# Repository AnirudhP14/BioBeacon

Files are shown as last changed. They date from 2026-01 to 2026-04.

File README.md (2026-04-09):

# BioBeacon

ESP32 based stigmergic swarm built on esp-now.

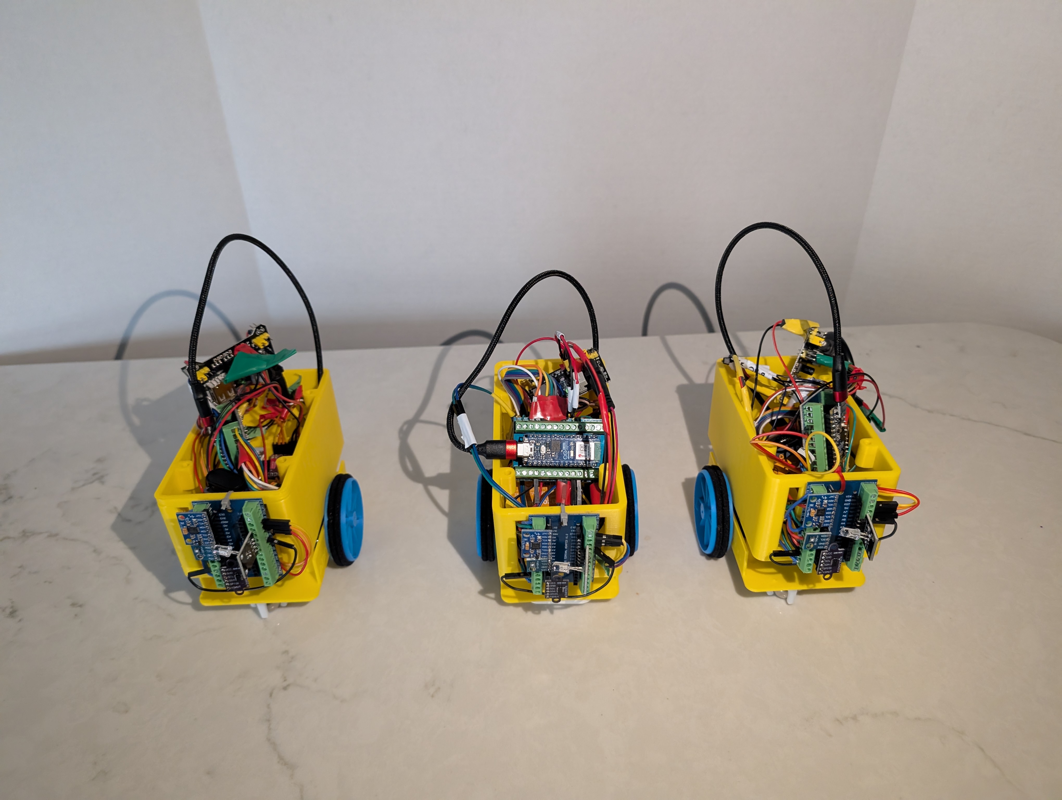
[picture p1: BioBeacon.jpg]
BioBeacon


# HiveMind - BioBeacon's swarm monitoring
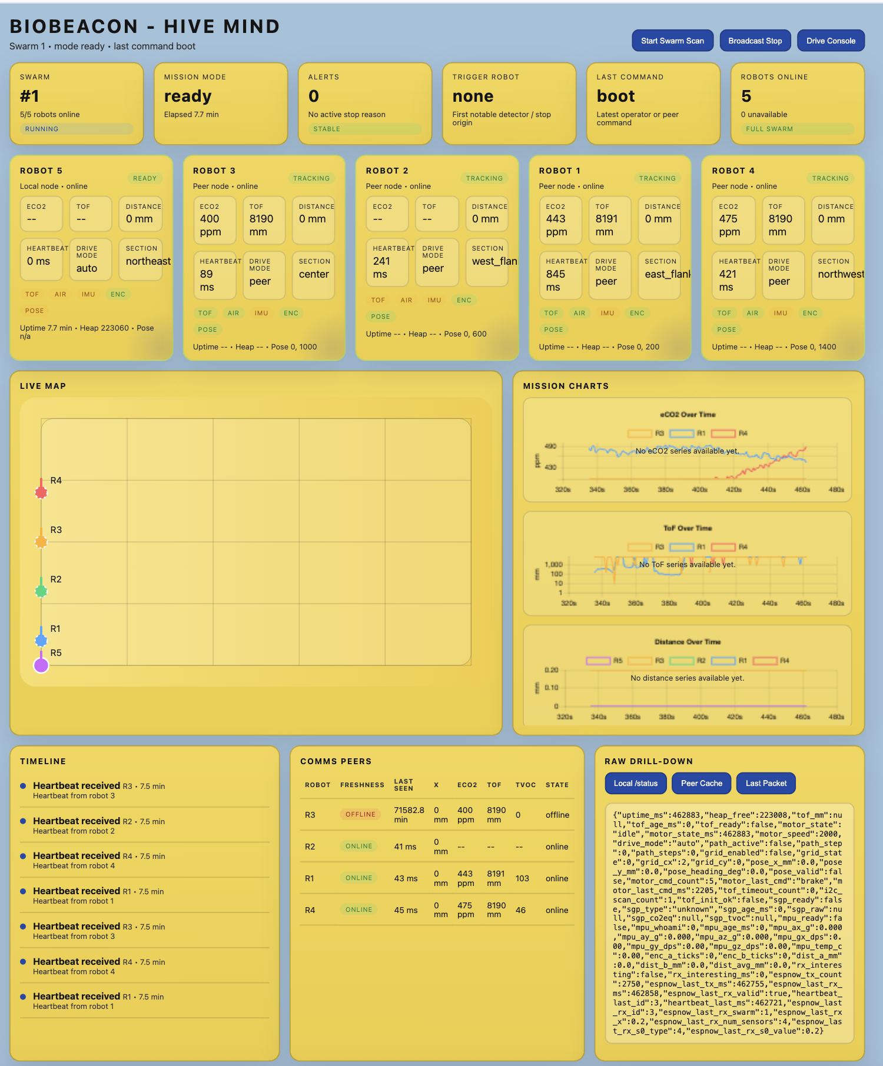
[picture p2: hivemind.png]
HiveMind


# Custom PCB for BioBeacob
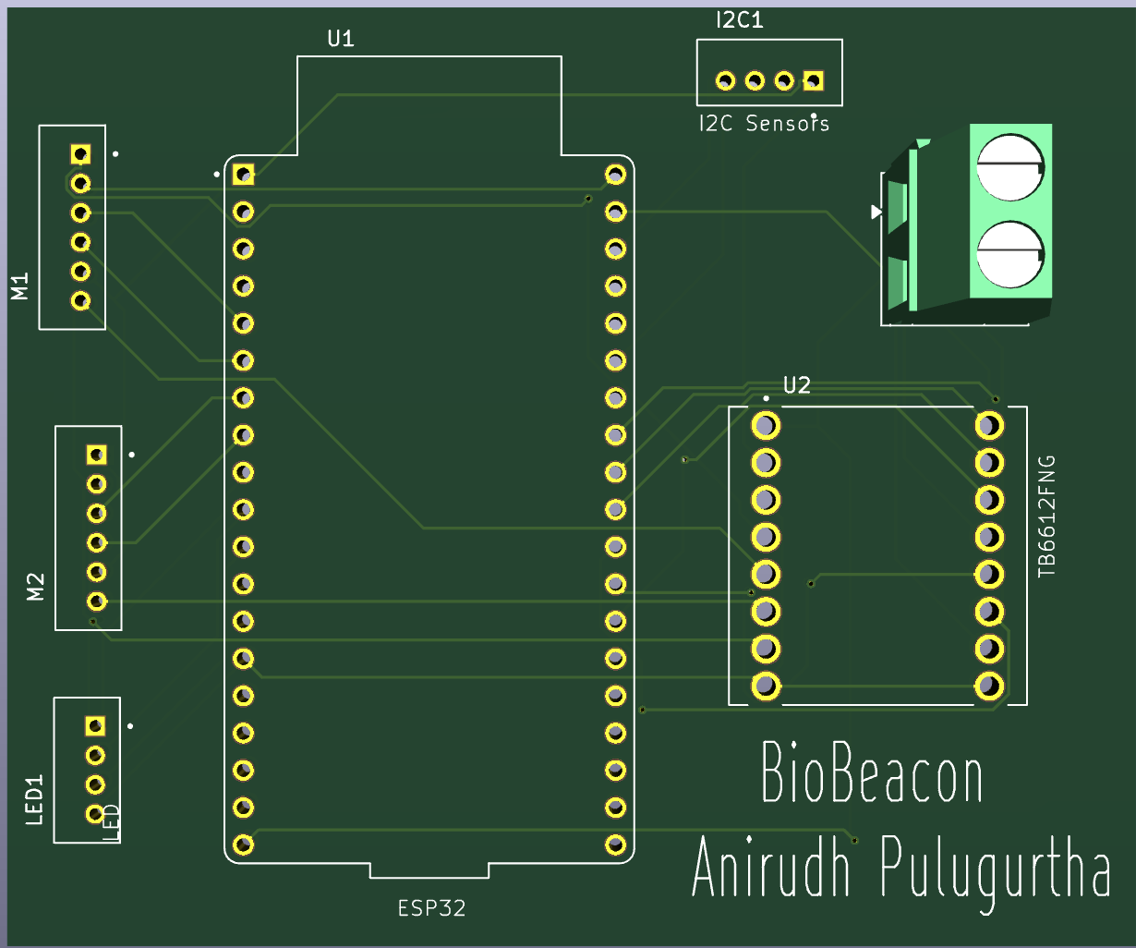
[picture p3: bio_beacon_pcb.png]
BioBeacon ESP32 PCB


white a01
red a02

white b01
red b02

Left motor encoder C1 → ENCA_C1 (GPIO2). green  D2
Left motor encoder C2 → ENCA_C2 (GPIO3).  yellow D3
Right motor encoder C1 → ENCB_C1 (GPIO11) green D11
Right motor encoder C2 → ENCB_C2 (GPIO12) yellow D12

Enc VCC - black 
Enc Gnd - purple

D0	GPIO44
D1	GPIO43
D2	GPIO5
D3	GPIO6
D4	GPIO7
D5	GPIO8
D6	GPIO9
D7	GPIO10
D8	GPIO17
D9	GPIO18
D10	GPIO21
D11	GPIO38
D12	GPIO47
D13	GPIO48
A0	GPIO1
A1	GPIO2
A2	GPIO3
A3	GPIO4
A4	GPIO11
A5	GPIO12
A6	GPIO13
A7	GPIO14
BOOT0	GPIO46
BOOT1	GPIO0

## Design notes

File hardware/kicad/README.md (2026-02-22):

# Kicad pcb files

This folder contains Ki-cad PCB files for
- BioBeacon ESP32 Wroom board
- BioBeacon sensor board - daughter board
- TB6612FNG motor board 

Additional ESP32 boards to be added to support additional ESP32 variants.
Separate TB6612FNG daughter board could provide more flexibility.

# Custom PCB for BioBeacob
BioBeacon ESP32 PCB

# Schematic for BioBeacon Motherboard 
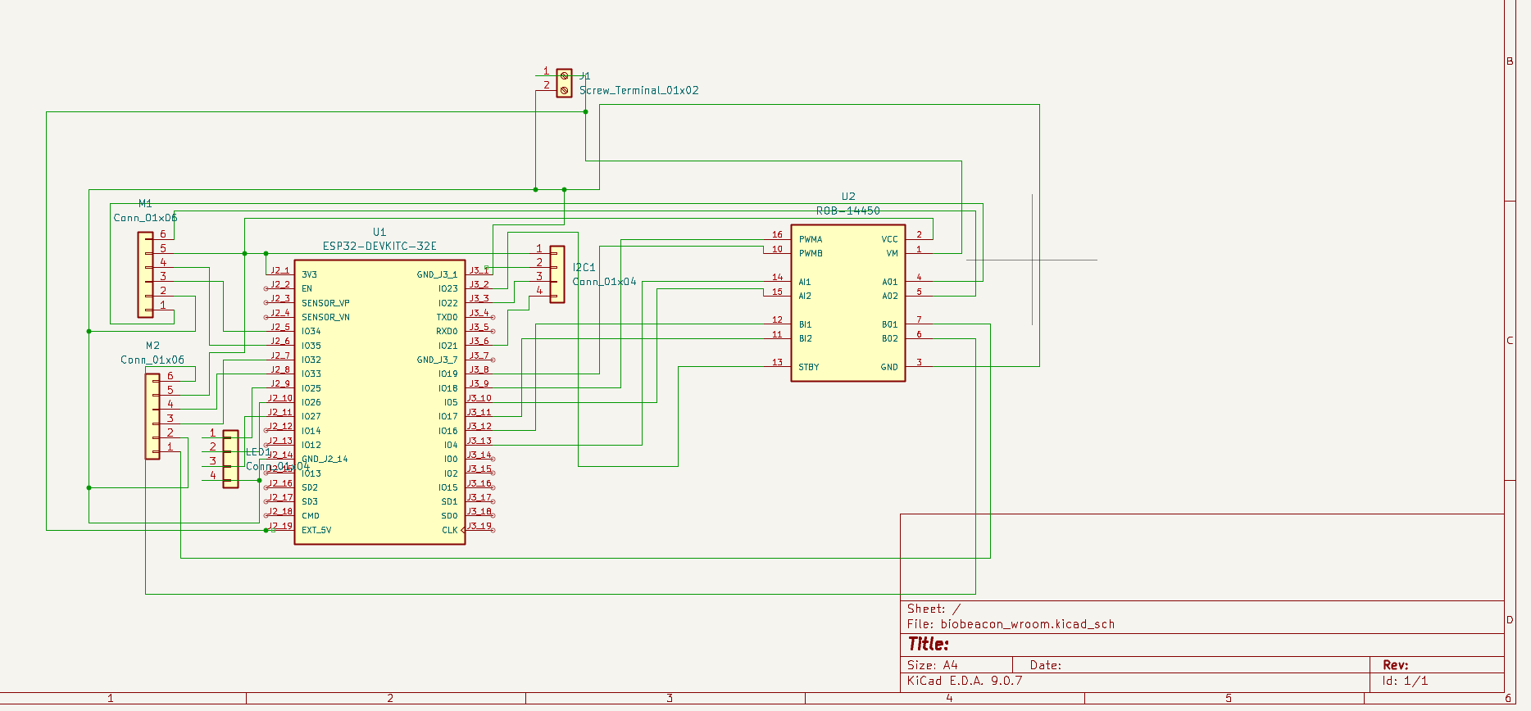
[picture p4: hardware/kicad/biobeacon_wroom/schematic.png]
BioBeacon Motherboard Schematic


# Sensorboard daugther board 
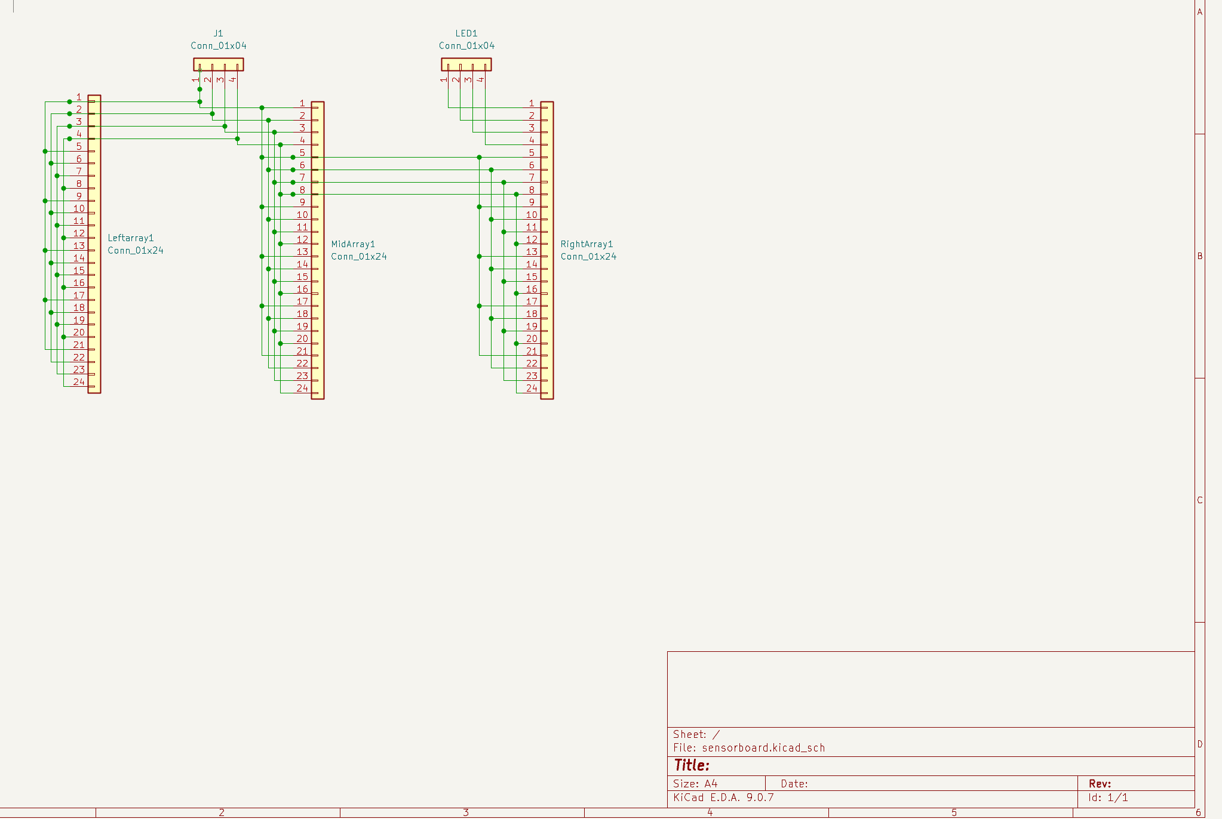
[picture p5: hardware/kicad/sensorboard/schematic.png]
BioBeacon sensorboard Schematic

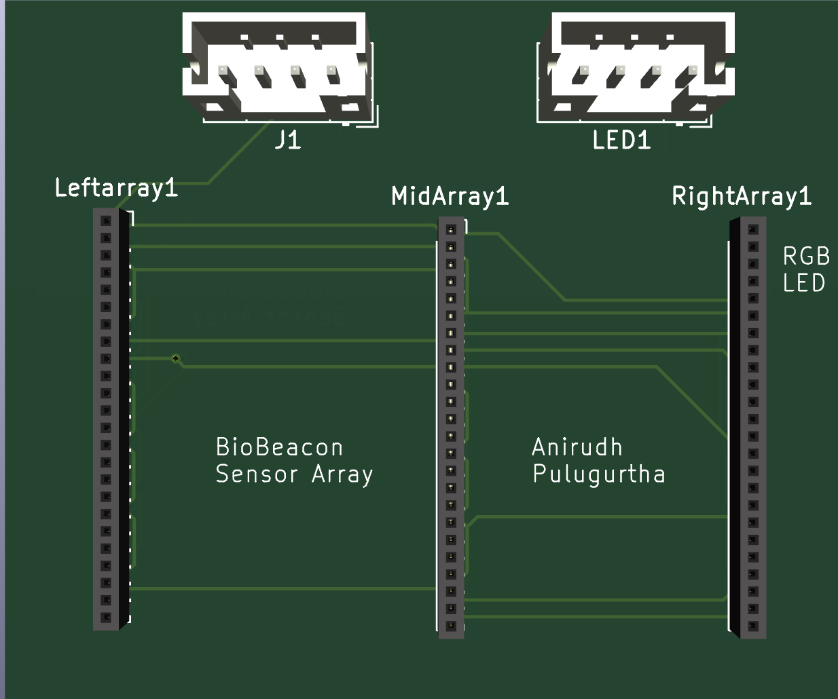
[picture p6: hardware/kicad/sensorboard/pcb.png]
BioBeacon sensorboard Schematic


# Motor driver daugther board 
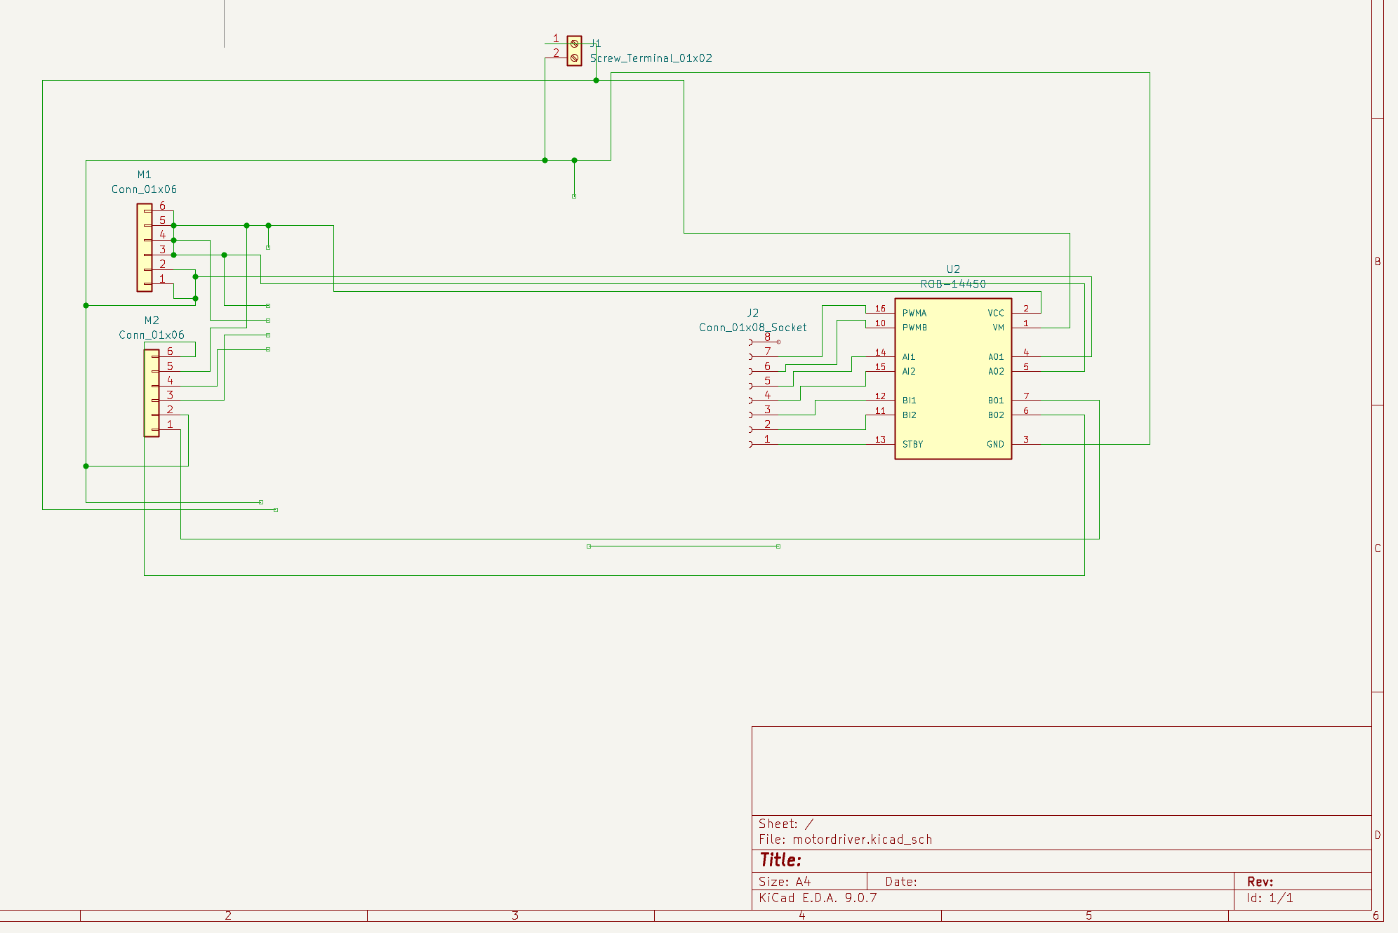
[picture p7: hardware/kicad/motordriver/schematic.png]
BioBeacon motordriver only Schematic

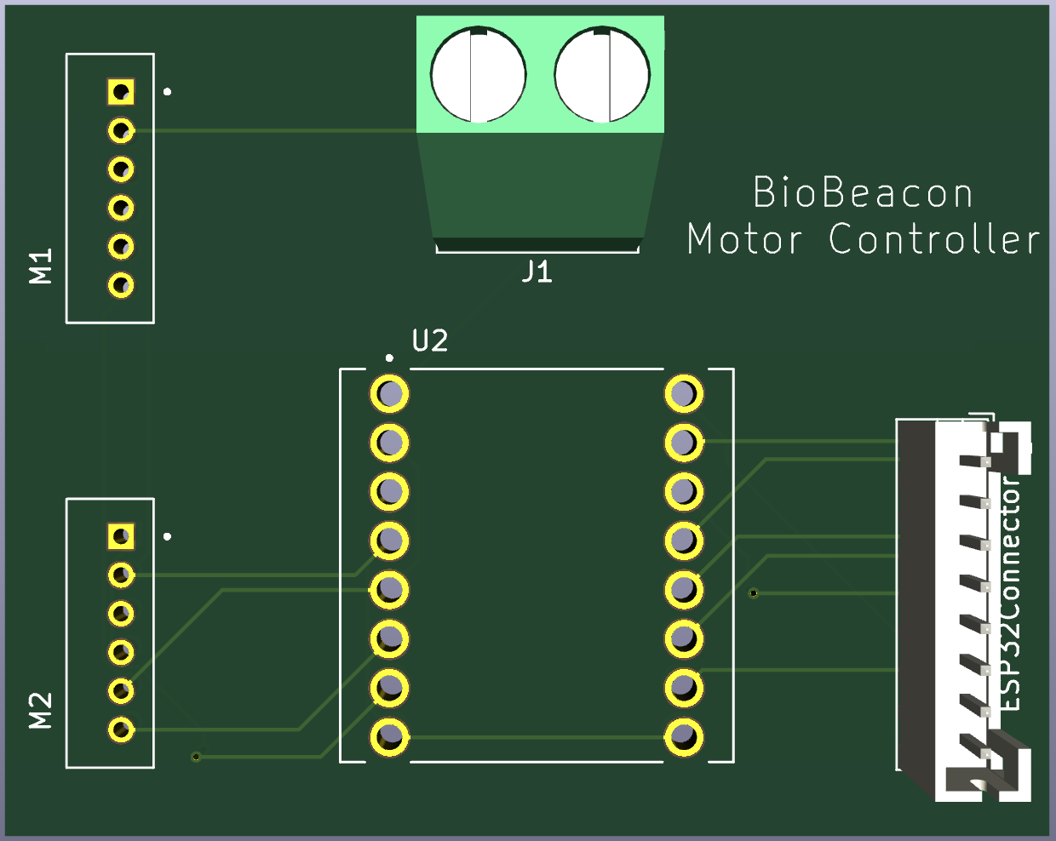
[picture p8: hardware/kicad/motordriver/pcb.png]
BioBeacon motordriver Schematic


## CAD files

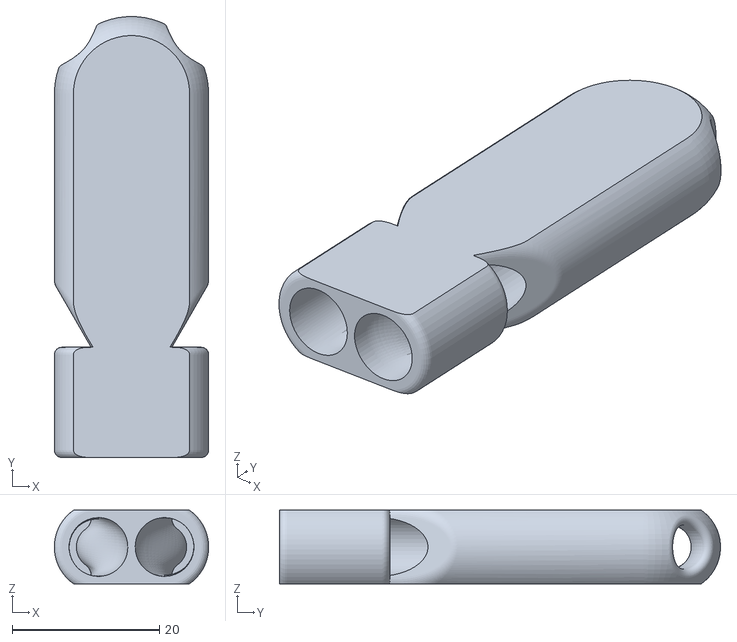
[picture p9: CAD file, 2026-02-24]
hardware/cad-3d-prints/rescue_tools_3d_print_files/whistle.stl
21.0 x 60.0 x 10.0

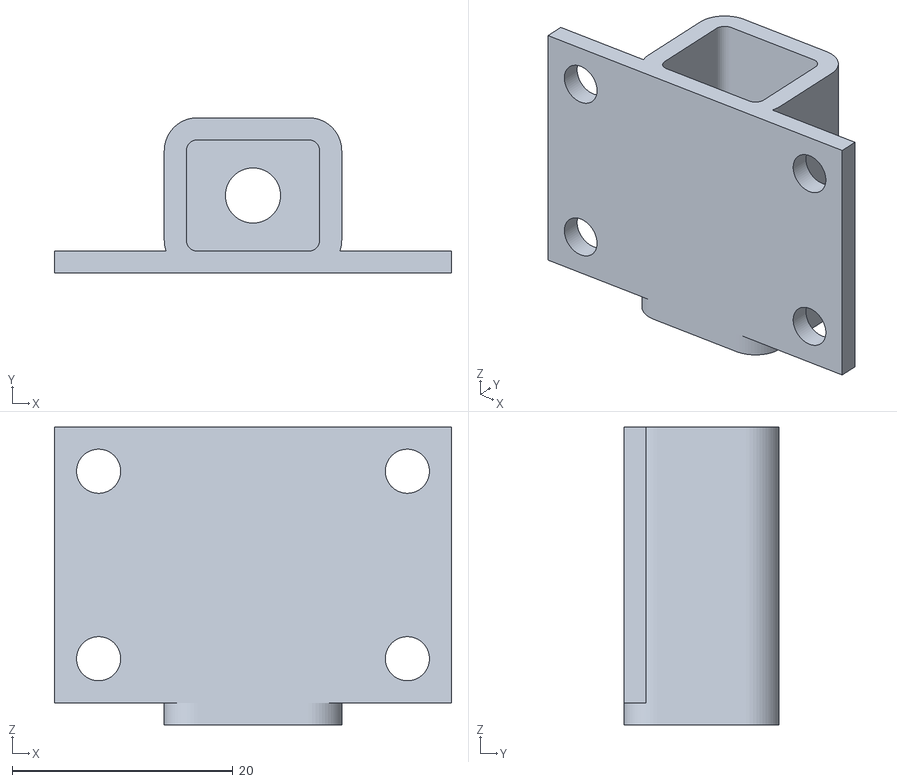
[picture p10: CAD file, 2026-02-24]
hardware/cad-3d-prints/robot_3d_print_files/N20MotorMounts.stl
36.0 x 14.1 x 27.0

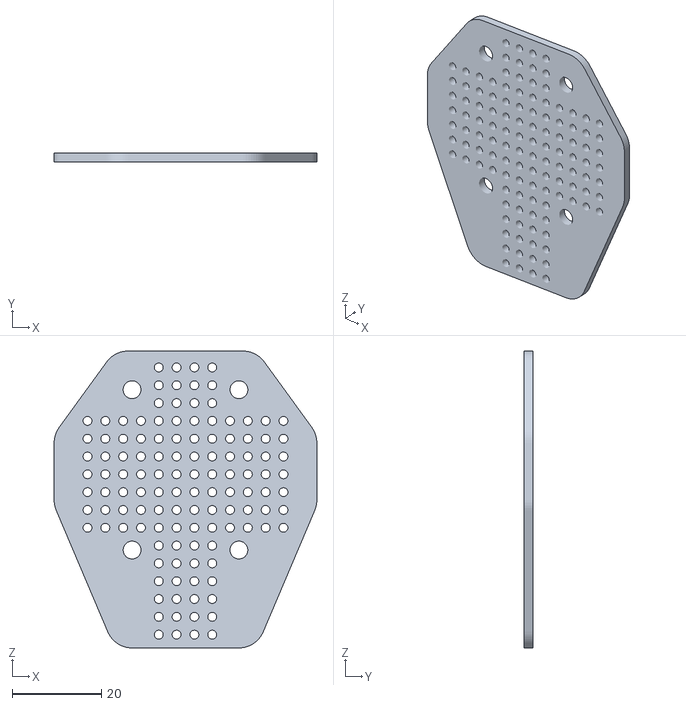
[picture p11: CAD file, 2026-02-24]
hardware/cad-3d-prints/robot_3d_print_files/robo_lid.stl
59.0 x 2.00 x 66.7

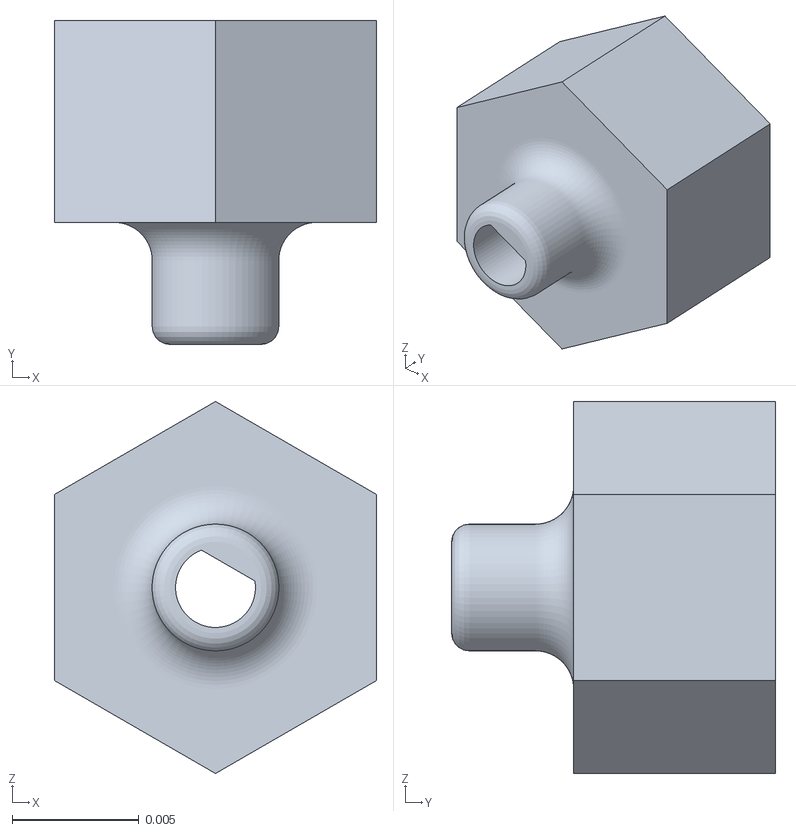
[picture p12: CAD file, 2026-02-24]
hardware/cad-3d-prints/robot_3d_print_files/Wheel.stl
0.0127 x 0.0128 x 0.0147

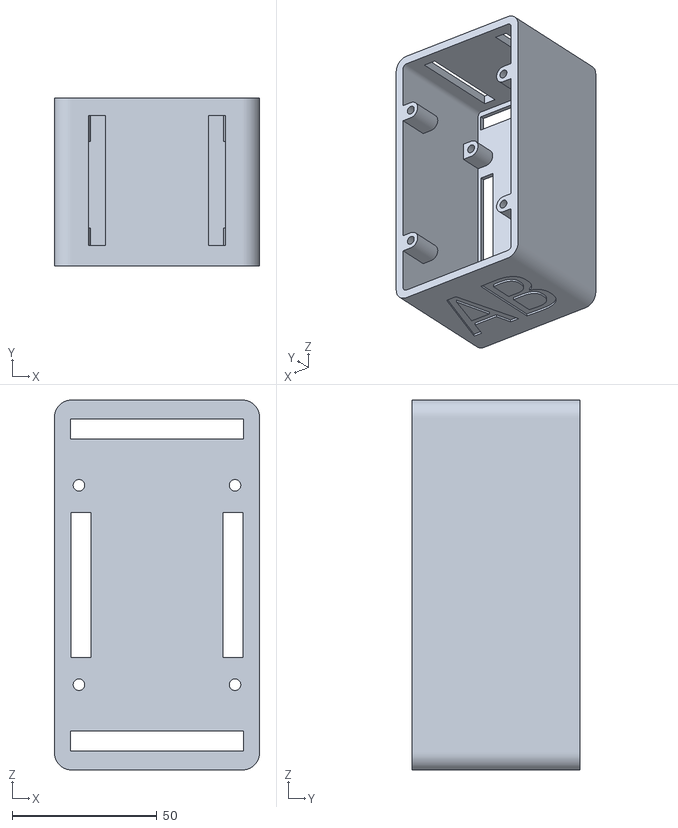
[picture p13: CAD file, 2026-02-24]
hardware/cad-3d-prints/robot_3d_print_files/robo_mid_box.stl
71.0 x 58.0 x 128.0

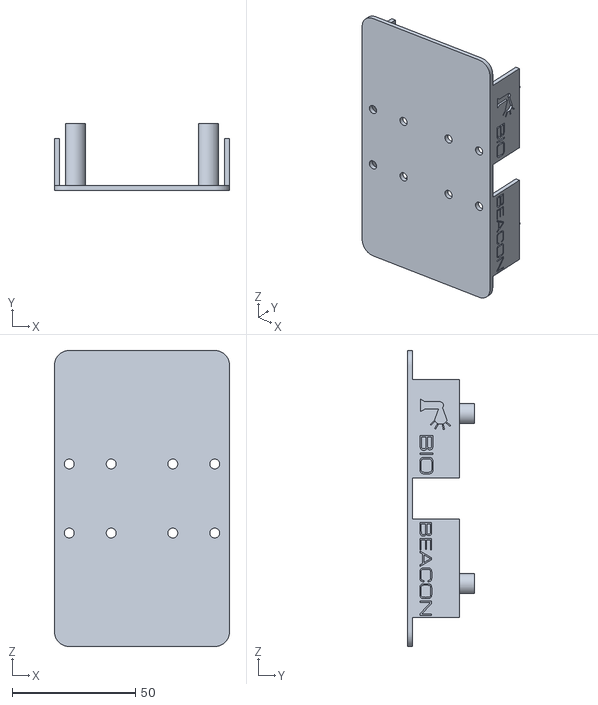
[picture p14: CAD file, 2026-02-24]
hardware/cad-3d-prints/robot_3d_print_files/robo_base.stl
71.0 x 27.0 x 120.0

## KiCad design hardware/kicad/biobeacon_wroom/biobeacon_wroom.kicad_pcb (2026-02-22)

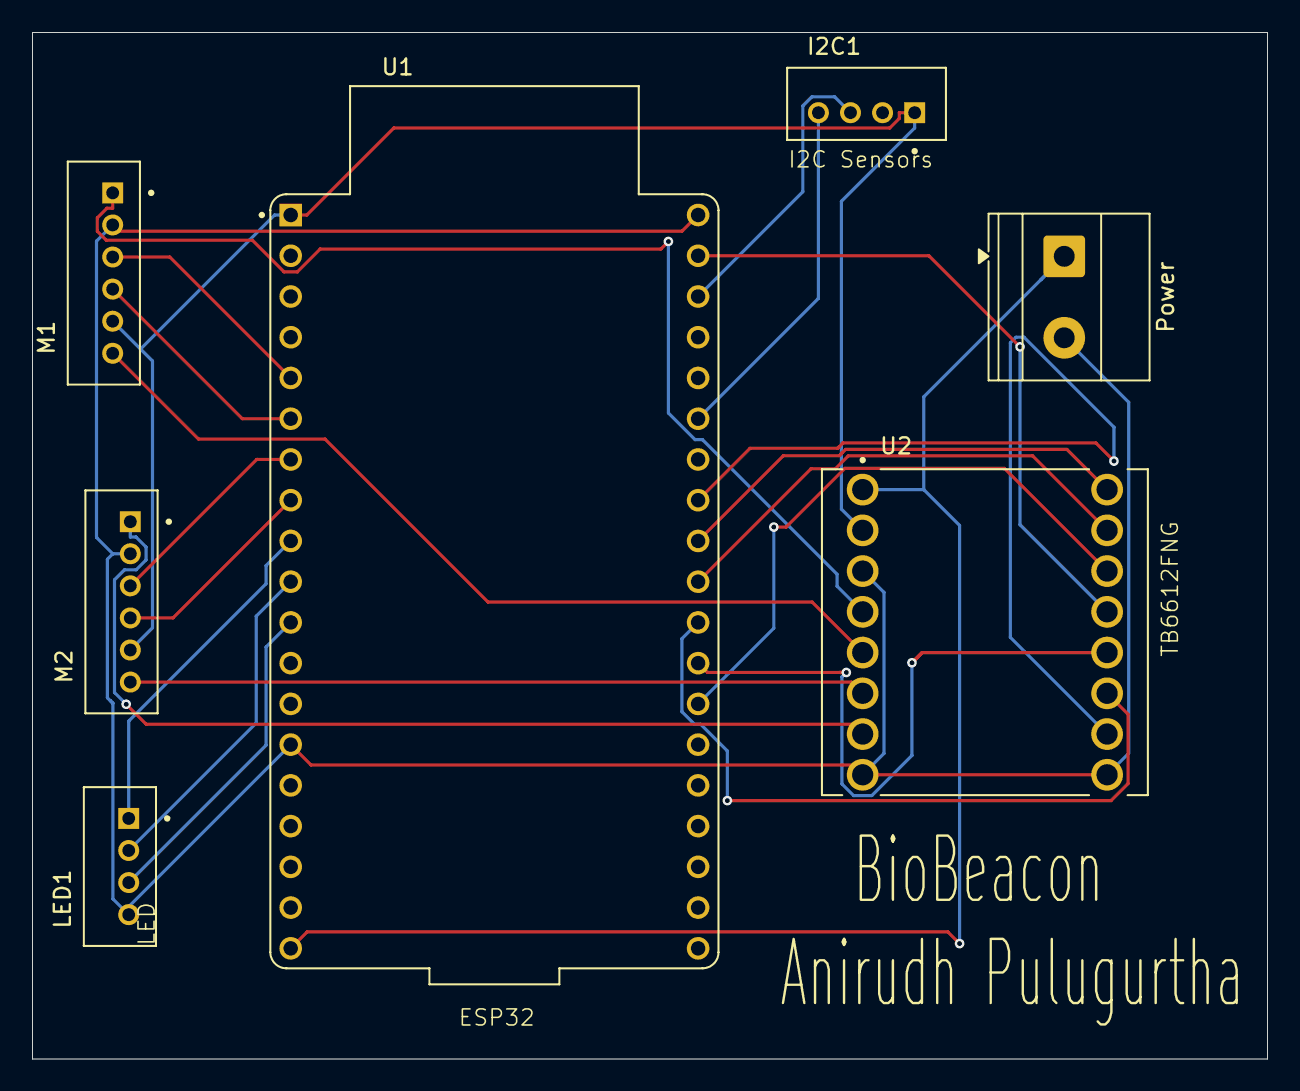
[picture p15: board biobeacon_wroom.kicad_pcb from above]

Board: 2 copper layers, 77.0 x 64.0 mm, 7 parts (0 on the bottom side), 23 nets.

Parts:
I2C1: Conn_01x04; JST_B4B-PH-K
LED1: Conn_01x04; JST_B4B-PH-K
M1, M2: Conn_01x06; JST_B6B-PH-K
Power: Screw_Terminal_01x02; TerminalBlock_Phoenix_MKDS-1,5-2-5.08_1x02_P5.08mm_Horizont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
U1: ESP32-DEVKITC-32E; MODULE_ESP32-DEVKITC-32E
U2: ROB-14450; MODULE_ROB-14450

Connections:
GND: LED1.4, M1.2, M2.2, Power.2, U1.J2_14 (GND_J2_14), U1.J3_1 (GND_J3_1), U2.3 (GND), U2.8 (GND), U2.9 (GND)
unnamed: I2C1.1, M1.5, M2.5, U1.J2_1 (3V3), U2.2 (VCC)
unnamed: I2C1.3, U1.J3_3 (IO22)
unnamed: I2C1.4, U1.J3_6 (IO21)
unnamed: Power.1, U1.J2_19 (EXT_5V), U2.1 (VM)
unnamed: LED1.1, U1.J2_9 (IO25)
unnamed: LED1.2, U1.J2_10 (IO26)
unnamed: LED1.3, U1.J2_11 (IO27)
unnamed: M1.1, U2.4 (A01)
unnamed: M1.3, U1.J2_5 (IO34)
unnamed: M1.4, U1.J2_6 (IO35)
unnamed: M1.6, U2.5 (A02)
unnamed: M2.1, U2.7 (B01)
unnamed: M2.3, U1.J2_7 (IO32)
unnamed: M2.4, U1.J2_8 (IO33)
unnamed: M2.6, U2.6 (B02)
unnamed: U1.J3_13 (IO4), U2.14 (AI1)
unnamed: U1.J3_10 (IO5), U2.15 (AI2)
unnamed: U1.J3_12 (IO16), U2.12 (BI1)
unnamed: U1.J3_11 (IO17), U2.11 (BI2)
unnamed: U1.J3_9 (IO18), U2.16 (PWMA)
unnamed: U1.J3_8 (IO19), U2.10 (PWMB)
unnamed: U1.J3_2 (IO23), U2.13 (STBY)

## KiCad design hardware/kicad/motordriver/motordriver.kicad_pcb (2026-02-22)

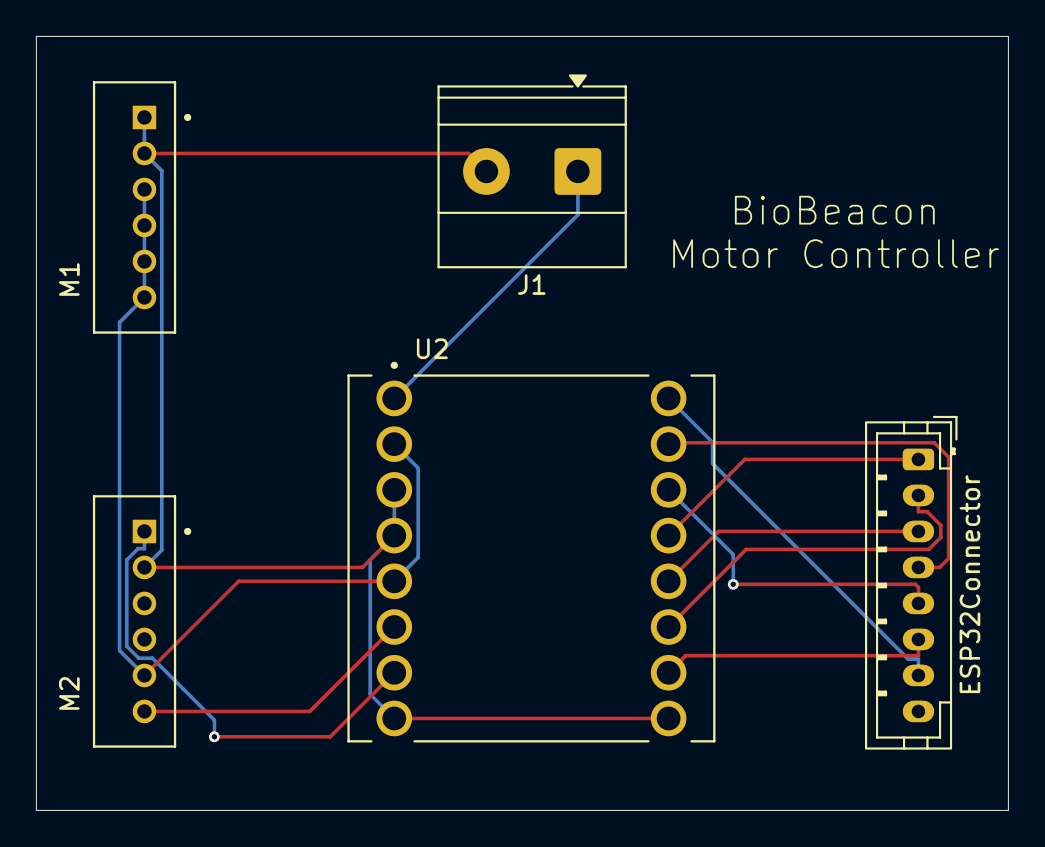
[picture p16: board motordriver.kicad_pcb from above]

Board: 2 copper layers, 54.0 x 43.0 mm, 5 parts (0 on the bottom side), 12 nets.

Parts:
ESP32Connector: Conn_01x08_Socket; JST_PH_B8B-PH-K_1x08_P2.00mm_Vertical
J1: Screw_Terminal_01x02; TerminalBlock_Phoenix_MKDS-1,5-2-5.08_1x02_P5.08mm_Horizont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
M1, M2: Conn_01x06; JST_B6B-PH-K
U2: ROB-14450; MODULE_ROB-14450

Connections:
GND: J1.2, M1.1, M1.2, M2.2, U2.3 (GND), U2.4 (A01), U2.8 (GND), U2.9 (GND)
unnamed: J1.1, U2.1 (VM)
unnamed: ESP32Connector.1, U2.13 (STBY)
unnamed: ESP32Connector.2, U2.11 (BI2)
unnamed: ESP32Connector.3, U2.12 (BI1)
unnamed: ESP32Connector.4, U2.15 (AI2)
unnamed: ESP32Connector.5, U2.14 (AI1)
unnamed: ESP32Connector.6, U2.10 (PWMB)
unnamed: ESP32Connector.7, U2.16 (PWMA)
unnamed: M1.3, M1.4, M1.5, M1.6, M2.5, U2.2 (VCC), U2.5 (A02)
unnamed: M2.1, U2.7 (B01)
unnamed: M2.6, U2.6 (B02)

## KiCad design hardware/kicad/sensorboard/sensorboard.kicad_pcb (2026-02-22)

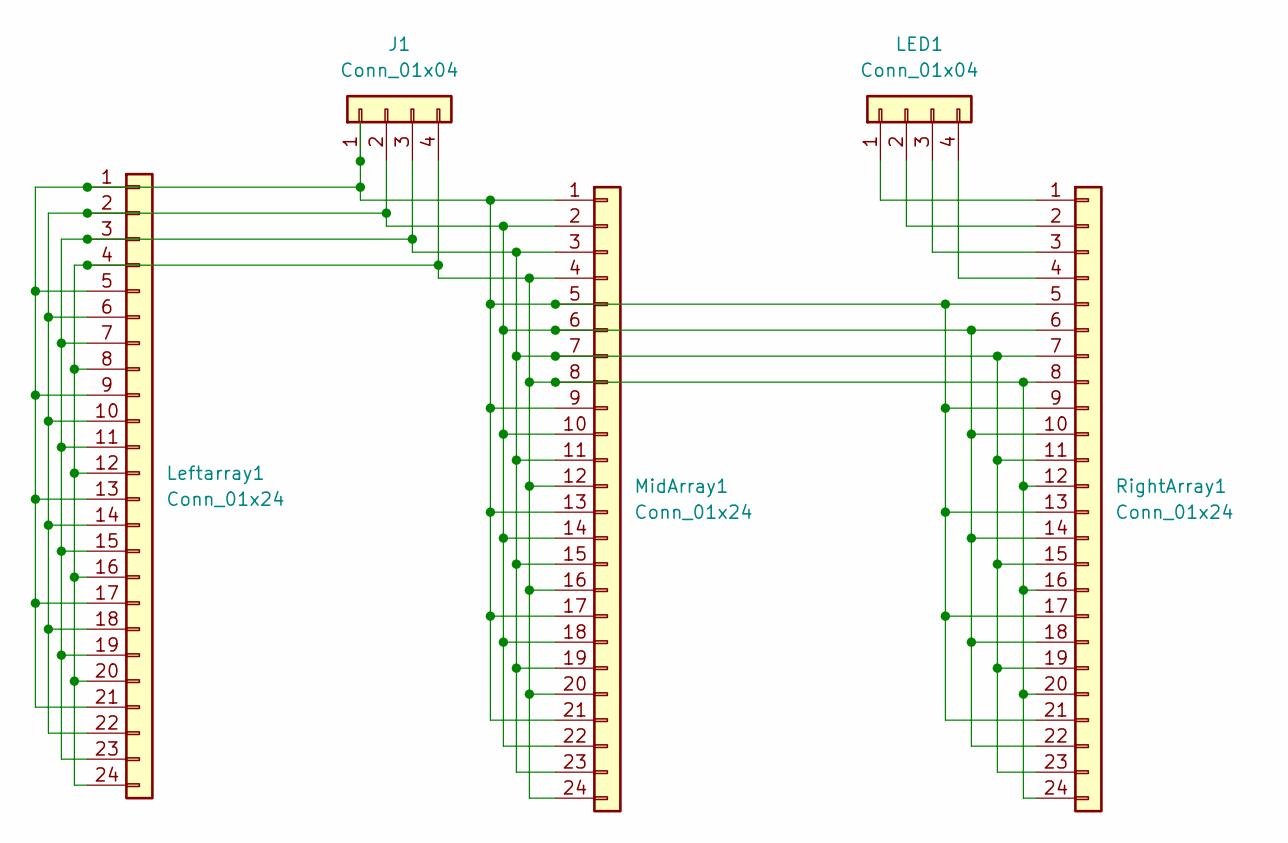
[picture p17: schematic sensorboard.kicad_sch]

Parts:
J1: Conn_01x04; JST_PH_B4B-PH-K_1x04_P2.00mm_Vertical
LED1: Conn_01x04; JST_PH_B4B-PH-K_1x04_P2.00mm_Vertical
Leftarray1: Conn_01x24; PinSocket_1x24_P1.00mm_Vertical
MidArray1: Conn_01x24; PinSocket_1x24_P1.00mm_Vertical
RightArray1: Conn_01x24; PinSocket_1x24_P1.00mm_Vertical

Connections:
unnamed: J1.1, Leftarray1.1, Leftarray1.5, Leftarray1.9, Leftarray1.13, Leftarray1.17, Leftarray1.21, MidArray1.1, MidArray1.5, MidArray1.9, MidArray1.13, MidArray1.17, MidArray1.21, RightArray1.5, RightArray1.9, RightArray1.13, RightArray1.17, RightArray1.21
unnamed: J1.2, Leftarray1.2, Leftarray1.6, Leftarray1.10, Leftarray1.14, Leftarray1.18, Leftarray1.22, MidArray1.2, MidArray1.6, MidArray1.10, MidArray1.14, MidArray1.18, MidArray1.22, RightArray1.6, RightArray1.10, RightArray1.14, RightArray1.18, RightArray1.22
unnamed: J1.3, Leftarray1.3, Leftarray1.7, Leftarray1.11, Leftarray1.15, Leftarray1.19, Leftarray1.23, MidArray1.3, MidArray1.7, MidArray1.11, MidArray1.15, MidArray1.19, MidArray1.23, RightArray1.7, RightArray1.11, RightArray1.15, RightArray1.19, RightArray1.23
unnamed: J1.4, Leftarray1.4, Leftarray1.8, Leftarray1.12, Leftarray1.16, Leftarray1.20, Leftarray1.24, MidArray1.4, MidArray1.8, MidArray1.12, MidArray1.16, MidArray1.20, MidArray1.24, RightArray1.8, RightArray1.12, RightArray1.16, RightArray1.20, RightArray1.24
unnamed: LED1.1, RightArray1.1
unnamed: LED1.2, RightArray1.2
unnamed: LED1.3, RightArray1.3
unnamed: LED1.4, RightArray1.4

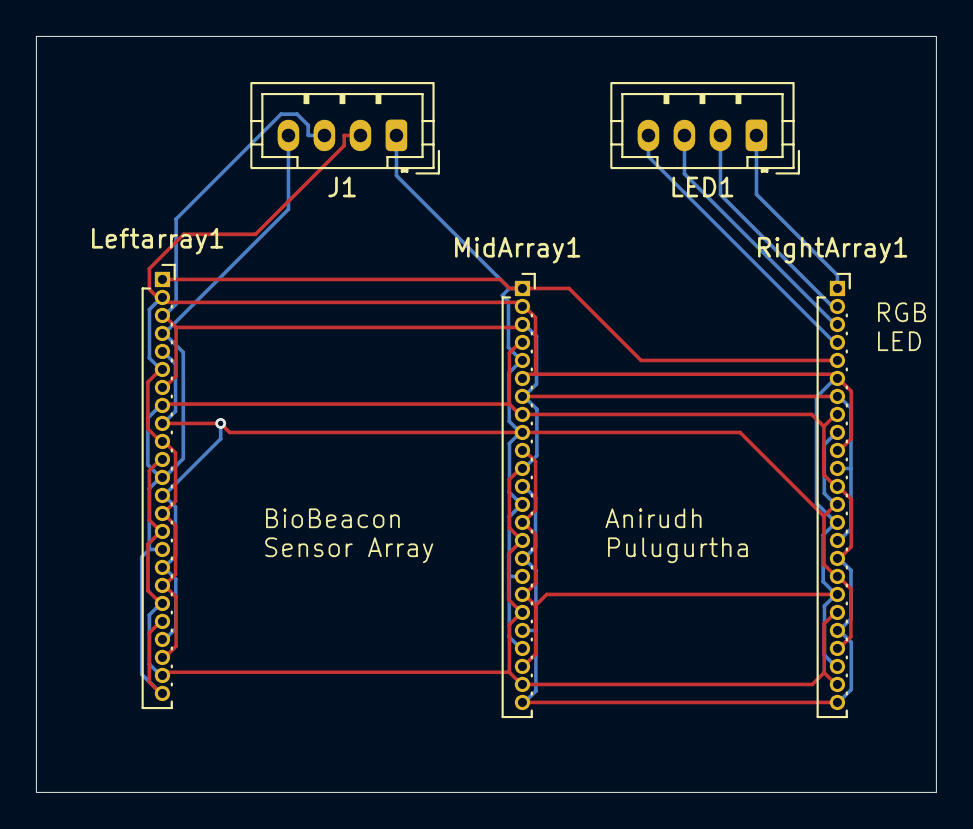
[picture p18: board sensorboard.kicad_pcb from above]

Board: 2 copper layers, 50.0 x 42.0 mm, 5 parts (0 on the bottom side), 8 nets.

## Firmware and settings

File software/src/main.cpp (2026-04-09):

#include <Arduino.h>
#include <WiFi.h>

#include "comms.h"
#include "config.h"
#include "diagnostics.h"
#include "dashboard_state.h"
#include "drive.h"
#include "grid_nav.h"
#include "led_controller.h"
#include "logging.h"
#include "motors.h"
#include "sensors.h"
#include "status_builder.h"
#include "web.h"

Logger logger;
LedController led(logger);
MotorDriver motors;
SensorManager sensors(logger);
DriveController drive(motors, logger);
GridNavigator gridNav(motors, sensors, logger);
EspNowManager comms(logger, motors, sensors, &led, &gridNav);
StatusBuilder statusBuilder(sensors, motors, drive, comms, gridNav);
DashboardState dashboard(logger, sensors, motors, drive, comms, gridNav, statusBuilder);
WebServerManager web(logger, drive, statusBuilder, gridNav, comms, dashboard);
Diagnostics diagnostics(logger, motors, sensors);

char wifiSsid[32];

void setupWiFi() {
  snprintf(wifiSsid, sizeof(wifiSsid), "%s-%u", config::WIFI_SSID_BASE, config::DEVICE_ID);
  WiFi.mode(WIFI_AP_STA);
  WiFi.softAP(wifiSsid, config::WIFI_PASS);

  IPAddress ip = WiFi.softAPIP();
  logger.logMsg("WiFi AP started");
  logger.logFmt("SSID: %s", wifiSsid);
  logger.logFmt("IP: %s", ip.toString().c_str());
}

void setup() {
  Serial.println("Booting...");
  delay(500);

  logger.logMsg("==== BOOT ====");
  logger.logFmt("Reset reason: %d", esp_reset_reason());
  randomSeed((uint32_t)ESP.getEfuseMac());

  setupWiFi();
  comms.begin();
  comms.attachDashboard(&dashboard);
  dashboard.begin(millis());
  web.begin();

  if (!led.begin()) {
    logger.logMsg("LED init failed");
    led.disable();
    logger.logMsg("LED controller disabled");
  }
  led.setBooting();
  // digitalWrite(config::LED_PIN_R, 255);
  // digitalWrite(config::LED_PIN_G, 0);
  // digitalWrite(config::LED_PIN_B, 0);

  motors.begin(logger);
  led.setColor(255, 0, 0);
  if (config::RUN_BOOT_DIAGNOSTICS) {
    diagnostics.logBootPins();
  }
  sensors.begin(config::RUN_BOOT_DIAGNOSTICS);
  led.setColor(0, 255, 0);
  gridNav.begin();

  logger.logMsg("Initializing motors");
  motors.forward(10);
  motors.brake();
  led.setColor(0, 0, 255);
  logger.logMsg("Motors initialized");

  if (config::RUN_BOOT_DIAGNOSTICS) {
    diagnostics.motorSelfTest();
  }

  led.setReady();
  logger.logMsg("Setup complete");
}

void loop() {
  web.handleClient();
  sensors.poll();

  unsigned long now = millis();
  dashboard.update(now);
  comms.update(now);
  if (config::ENABLE_GRID_NAV && gridNav.isEnabled()) {
    gridNav.update(now);
  } else {
    drive.setAvoid(comms.isAvoiding(now));
    drive.update(now);
  }

  SensorStatus s = sensors.status();
  static bool lastDriveActive = false;
  bool driveActive =
      (config::ENABLE_GRID_NAV && gridNav.isEnabled()) ||
      (drive.status().driveMode == DriveMode::Path);
  if (driveActive != lastDriveActive) {
    if (driveActive) {
      led.setDriveMode();
      led.setStop(false);
    } else {
      led.setReady();
    }
    lastDriveActive = driveActive;
  }
  static bool co2Latched = false;
  if (s.sgpHasAir) {
    if (!co2Latched && s.sgpCO2 > 500) co2Latched = true; //1000 for artifcial co2 source
    if (co2Latched && s.sgpCO2 < 450) co2Latched = false; //800 for turning off
  }
  led.setCO2High(web.co2TestEnabled() ? true : co2Latched);
  CommsStatus commsStatus = comms.status();
  led.setRemoteCO2(commsStatus.remoteCo2Alert);
  if (gridNav.isScanStopLatched()) {
    led.setStop(true);
  }
  static bool scanStopSent = false;
  if (!gridNav.isScanStopLatched()) {
    scanStopSent = false;
  } else if (!scanStopSent) {
    if (gridNav.scanStopTofMm() > 0 && gridNav.scanStopTofMm() < config::SCAN_TOF_STOP_MM) {
      comms.sendStop();
      char detail[64];
      snprintf(detail, sizeof(detail), "ToF stop at %u mm", gridNav.scanStopTofMm());
      dashboard.onScanStop(detail, now);
      logger.logFmt(
          "Grid scan ToF stop after %.1fs (ToF=%u mm)",
          gridNav.scanStopElapsedSec(),
          gridNav.scanStopTofMm());
    } else if (gridNav.scanStopPpm() > config::SCAN_CO2_STOP_PPM) {
      comms.sendStop();
      char detail[64];
      snprintf(detail, sizeof(detail), "CO2 stop at %u ppm", gridNav.scanStopPpm());
      dashboard.onScanStop(detail, now);
      logger.logFmt(
          "Grid scan CO2 stop after %.1fs (CO2=%u ppm)",
          gridNav.scanStopElapsedSec(),
          gridNav.scanStopPpm());
    }
    scanStopSent = true;
  }
  led.update(now);
}

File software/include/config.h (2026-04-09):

#ifndef SWARMBOT_CONFIG_H
#define SWARMBOT_CONFIG_H

#include <Arduino.h>
#include "pins.h"

namespace config {
constexpr bool RUN_BOOT_DIAGNOSTICS = true;

constexpr const char* WIFI_SSID_BASE = "firefly";
constexpr const char* WIFI_PASS = "debug123";


// ESP-NOW
constexpr uint8_t DEVICE_ID = 5;
constexpr uint8_t SWARM_ID = 1;
constexpr uint8_t EXPECTED_ROBOTS = 5;

constexpr int OFFSET_A = 1;
constexpr int OFFSET_B = 1;
constexpr int ALIGN_A = (DEVICE_ID == 1) ? 1 : -1; //used to be 3 here
constexpr int ALIGN_B = -1; // (DEVICE_ID == 1) ? 1 : -1;   

constexpr float WHEEL_DIAM_MM = 53.0f;
constexpr int QUADRATURE = 4;
constexpr int ENCODER_PPR = 1050 * QUADRATURE;
constexpr float MM_PER_TICK = (PI * WHEEL_DIAM_MM) / ENCODER_PPR;

// Drive timings/speeds
constexpr unsigned long FORWARD_TIME_MS = 1000;
constexpr unsigned long BACKWARD_TIME_MS = 1000;
constexpr unsigned long BRAKE_TIME_MS = 1000;
constexpr int DRIVE_SPEED = 2000;
constexpr int TURN_SPEED = 1600;
constexpr unsigned long RANDOM_STEP_MIN_MS = 300;
constexpr unsigned long RANDOM_STEP_MAX_MS = 900;
constexpr int MAX_PATH_STEPS = 16;

// Grid navigation
constexpr bool ENABLE_GRID_NAV = false;
constexpr int GRID_WIDTH = 5;
constexpr int GRID_HEIGHT = 4;
constexpr float CELL_WIDTH_MM = 500.0f;
constexpr float CELL_HEIGHT_MM = 500.0f;
constexpr float BOUNDARY_MARGIN_MM = 50.0f;
constexpr float POSITION_TOLERANCE_MM = 60.0f;
constexpr float HEADING_TOLERANCE_DEG = 12.0f;
constexpr float HEADING_KP = 0.8f;

constexpr float MAX_X_MM = GRID_WIDTH * CELL_WIDTH_MM;
constexpr float MAX_Y_MM = GRID_HEIGHT * CELL_HEIGHT_MM;
constexpr float SPEED_MM_PER_SEC = 150.0f;  // Calibrate: measure time for 300mm straight, speed = 300 / time_sec
constexpr float TIMED_FORWARD_SEC_PER_CELL = 1.25f;  // Calibrate: time to move one cell forward 1.25
constexpr float TIMED_TURN_90_SEC = 0.285f;           // Calibrate: time for 90 deg spot turn at TURN_SPEED 0.25 (0.31 for dev 1)
constexpr int TIMED_DRIVE_SPEED = 500;             // PWM value
constexpr unsigned long SCAN_BRAKE_MS = 500;

constexpr uint8_t SENSOR_CO2 = 1;
constexpr uint8_t SENSOR_TVOC = 2;
constexpr uint8_t SENSOR_TOF = 3;
constexpr uint8_t SENSOR_DIST = 4;
constexpr uint8_t SENSOR_HEARTBEAT = 250;
constexpr unsigned long ESP_NOW_PERIOD_MS = 200;
constexpr unsigned long ESP_NOW_HEARTBEAT_MS = 1000;
constexpr float NEARBY_MM = 200.0f;
constexpr float CO2_ALERT = 1000.0f;
constexpr uint16_t SCAN_CO2_STOP_PPM = 600;
constexpr uint16_t SCAN_TOF_STOP_MM = 200;
}  // namespace config

#endif  // SWARMBOT_CONFIG_H

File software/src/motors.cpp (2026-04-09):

#include "motors.h"

#include <TB6612_ESP32.h>
#include "config.h"
#include "logging.h"

namespace {
volatile long encoderATicks = 0;
volatile long encoderBTicks = 0;

Motor motor1(config::AIN1, config::AIN2, config::PWMA, config::OFFSET_A, config::STBY, 5000, 8, 0);
Motor motor2(config::BIN1, config::BIN2, config::PWMB, config::OFFSET_B, config::STBY, 5000, 8, 1);

void IRAM_ATTR encoderAIsr() {
  int a = digitalRead(config::ENCA_C1);
  int b = digitalRead(config::ENCA_C2);
  encoderATicks += (a == b) ? 1 : -1;
}

void IRAM_ATTR encoderBIsr() {
  int a = digitalRead(config::ENCB_C1);
  int b = digitalRead(config::ENCB_C2);
  encoderBTicks += (a == b) ? -1 : 1;
}
}  // namespace

const char* motorStateLabel(MotorState state) {
  switch (state) {
    case MotorState::Idle: return "idle";
    case MotorState::Forward: return "forward";
    case MotorState::Backward: return "backward";
    case MotorState::Brake: return "brake";
    case MotorState::TurnLeft: return "turn_left";
    case MotorState::TurnRight: return "turn_right";
    default: return "unknown";
  }
}

void MotorDriver::begin(Logger& log) {
  log_ = &log;
  pinMode(config::STBY, OUTPUT);
  digitalWrite(config::STBY, HIGH);
  pinMode(config::ENCA_C1, INPUT_PULLUP);
  pinMode(config::ENCA_C2, INPUT_PULLUP);
  pinMode(config::ENCB_C1, INPUT_PULLUP);
  pinMode(config::ENCB_C2, INPUT_PULLUP);
  attachInterrupt(digitalPinToInterrupt(config::ENCA_C1), encoderAIsr, CHANGE);
  attachInterrupt(digitalPinToInterrupt(config::ENCB_C1), encoderBIsr, CHANGE);
  log.logFmt("Encoders initialized, STBY=%d", digitalRead(config::STBY));
}

void MotorDriver::driveMotors(int m1, int m2, MotorState state, const char* label) {
  digitalWrite(config::STBY, HIGH);
  if (log_) {
    log_->logFmt(label, m1, m2);
  }
  motor1.drive(m1);
  motor2.drive(m2);
  commandCount_++;
  lastCmdMs_ = millis();
  lastCmdState_ = state;
}

void MotorDriver::forward(int speed) {
  int s = speed;
  if (s < 0) s = -s;
  if (s > 255) s = 255;
  int m1 = s * config::ALIGN_A;
  int m2 = s * config::ALIGN_B;
  driveMotors(m1, m2, MotorState::Forward, "Motor cmd forward m1=%d m2=%d");
}

void MotorDriver::backward(int speed) {
  int s = speed;
  if (s < 0) s = -s;
  if (s > 255) s = 255;
  int m1 = -s * config::ALIGN_A;
  int m2 = -s * config::ALIGN_B;
  driveMotors(m1, m2, MotorState::Backward, "Motor cmd backward m1=%d m2=%d");
}

void MotorDriver::brake() {
  digitalWrite(config::STBY, HIGH);
  motor1.brake();
  motor2.brake();
  commandCount_++;
  lastCmdMs_ = millis();
  lastCmdState_ = MotorState::Brake;
}

void MotorDriver::turnLeft(int speed) {
  int s = speed;
  if (s < 0) s = -s;
  if (s > 255) s = 255;
  int m1 = -s * config::ALIGN_A;
  int m2 = s * config::ALIGN_B;
  driveMotors(m1, m2, MotorState::TurnLeft, "Motor cmd left turn m1=%d m2=%d");
}

void MotorDriver::turnRight(int speed) {
  int s = speed;
  if (s < 0) s = -s;
  if (s > 255) s = 255;
  int m1 = s * config::ALIGN_A;
  int m2 = -s * config::ALIGN_B;
  driveMotors(m1, m2, MotorState::TurnRight, "Motor cmd right turn m1=%d m2=%d");
}

void MotorDriver::driveRaw(int leftSpeed, int rightSpeed, MotorState state) {
  int m1 = leftSpeed;
  int m2 = rightSpeed;
  if (m1 > 255) m1 = 255;
  if (m1 < -255) m1 = -255;
  if (m2 > 255) m2 = 255;
  if (m2 < -255) m2 = -255;
  driveMotors(m1, m2, state, "Motor cmd raw m1=%d m2=%d");
}

EncoderStatus MotorDriver::getEncoderStatus() const {
  EncoderStatus status;
  noInterrupts();
  status.aTicks = encoderATicks;
  status.bTicks = encoderBTicks;
  interrupts();
  status.aDistMm = status.aTicks * config::MM_PER_TICK;
  status.bDistMm = status.bTicks * config::MM_PER_TICK;
  status.avgDistMm = (status.aDistMm + status.bDistMm) * 0.5f;
  return status;
}

unsigned long MotorDriver::commandCount() const {
  return commandCount_;
}

unsigned long MotorDriver::lastCommandMs() const {
  return lastCmdMs_;
}

MotorState MotorDriver::lastCommandState() const {
  return lastCmdState_;
}

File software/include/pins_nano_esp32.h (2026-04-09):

#ifndef SWARMBOT_PINS_NANO_ESP32_H
#define SWARMBOT_PINS_NANO_ESP32_H

#include <Arduino.h>

namespace config {
// Motor driver pins (Arduino Nano ESP32 pin labels -> GPIO)
constexpr int AIN1 = 5;
constexpr int AIN2 = 6;
constexpr int PWMA = 9;
constexpr int BIN1 = 7;
constexpr int BIN2 = 8;
constexpr int PWMB = 10;
constexpr int STBY = 4;

// Encoder pins (C1/C2)
constexpr int ENCA_C1 = 2;
constexpr int ENCA_C2 = 3;
constexpr int ENCB_C1 = 11;
constexpr int ENCB_C2 = 12;

// RGB LED pins (common cathode)
constexpr int LED_PIN_R = A0;  // A6 to A0
constexpr int LED_PIN_G = A6;  // A7 to A1
constexpr int LED_PIN_B = A7;  // TX1 to D13 to A2

// I2C pins (use core defaults for Nano ESP32)
constexpr int SDA_PIN = SDA;
constexpr int SCL_PIN = SCL;
}  // namespace config

#endif  // SWARMBOT_PINS_NANO_ESP32_H

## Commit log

2026-02-22 kicad schematics and pcb design files
    [biobeacon_wroom.kicad_pcb, biobeacon_wroom.kicad_sch, motordriver.kicad_pcb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]
2026-02-22 biobeacon pcb render
2026-02-24 3d prints of robot and survival tools
    [N20MotorMounts.stl, Wheel.stl, robo_base.stl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]
